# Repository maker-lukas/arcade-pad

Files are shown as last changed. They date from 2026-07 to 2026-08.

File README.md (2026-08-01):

# Pac Pad

> A small arcade pad to play your favorite retro games!

---

This is a small arcade pad i designed and built with hardware i already owned so some of the parts could be better but this is what i had. The layout is a 6x2 button arrangement which covers all the retro classics, plus i added 2 extra buttons on the side for pinball games!! The joystick is just a generic analog module and not a proper arcade joystick but it does the job. For the top panel i used plywood instead of printing it to save on filament and honestly it gives it a nice little look.

for the brains it's running on a ESP32 C3 Super Mini which is not ideal because it doesn't support native USB HID, so i have to power it and connect over BLE bluetooth which adds some latency but its fine for what this is.

## Bill Of Material

| Part | Quantity | Price | Link |
|---|---|---|---|
| 30mm Arcade Button | 8 | $6.21 | [aliexpress](https://aliexpress.com/item/1005010285560262.html) |
| 12mm Tactile Button | 2 | $2.98 | [aliexpress](https://aliexpress.com/item/1005004781630944.html) |
| HW-504 Joystick Module | 1 | $1.81 | [aliexpress](https://aliexpress.com/item/1005006966359366.html) |
| ESP32 C3 Super Mini | 1 | $12.79  | [amazon](https://www.amazon.es/dp/B0DMNBWTFD) |
| Aluminium Tube OD: 10mm ID: 6mm Lenght 500mm | 1 | $5.73 | [aliexpress](https://aliexpress.com/item/1005011781231742.html) |
| m3x14 screws | 10 | $2.23 | [aliexpress](https://aliexpress.com/item/1005005112411362.html) |
| 6.5mm Plywood ~250x150mm | 1 | ~$1 | Local Hardware Store |
| Pin Header 3pins | 1 | $2.12 | [aliexpress](https://aliexpress.com/item/1005008406352332.html) |
| Silicon Wires | 2 | $13.51  | [aliexpress](https://aliexpress.com/item/1005005450546335.html) |
| Female to Female Jumper Cable | 4 | $1.06 | [aliexpress](https://aliexpress.com/item/1005004631908016.html) |
| 3D Printed Parts | 13 | N/A | N/A |
| **Total:** | | ~$49.44 | |

## Flashing

```sh
pip install esptool
esptool.py --chip esp32c3 --port <port> write_flash 0x0 Firmware/Build/pac-pad.ino.merged.bin

Replace `<port>` with your port (e.g. `COM3`, `/dev/ttyACM0`, `/dev/ttyUSB0`).
```

## Overview

| **Schematic**                       |
|:-----------------------------------:|
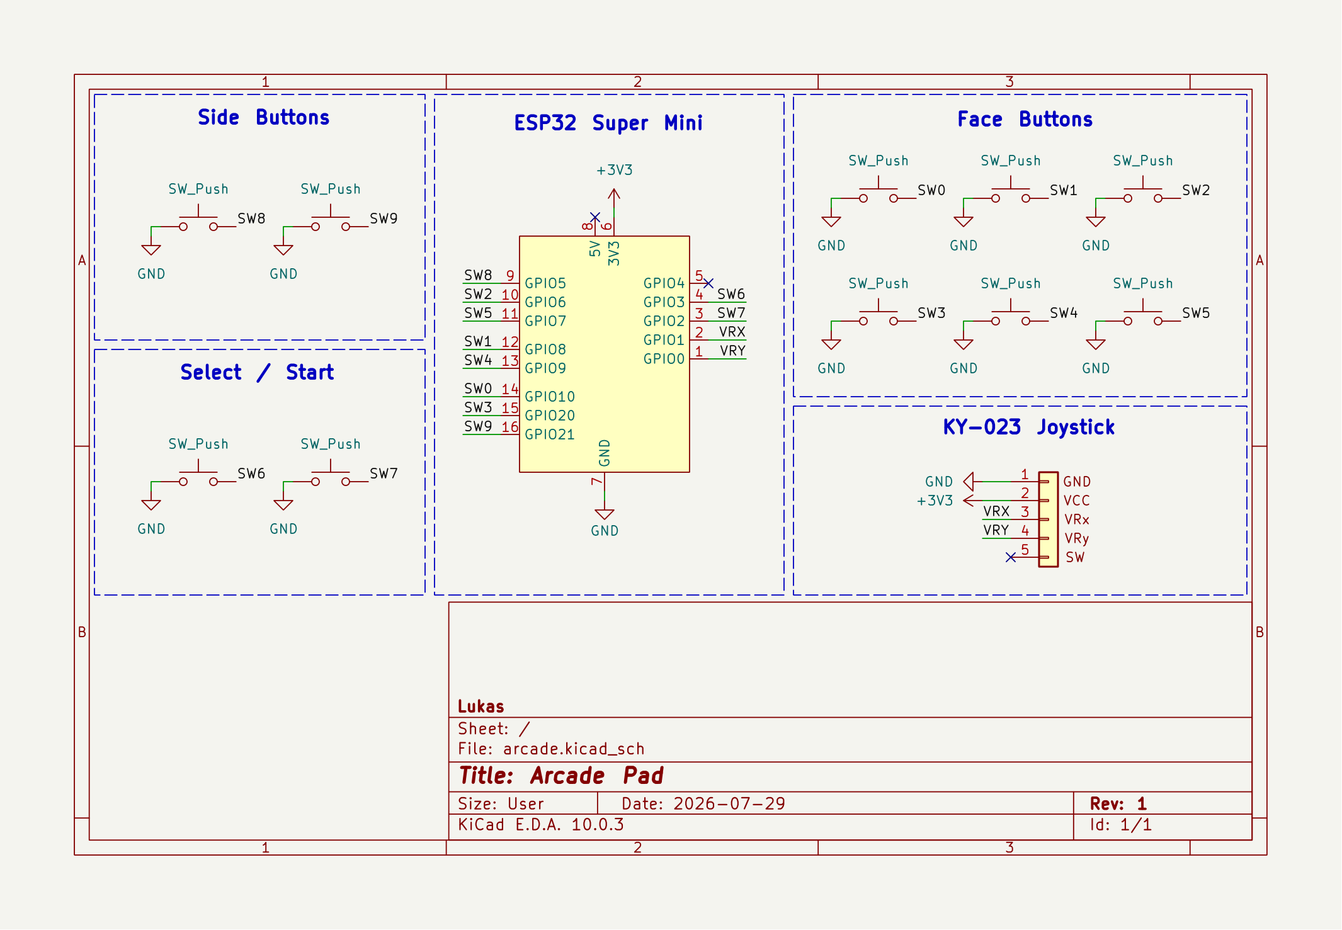
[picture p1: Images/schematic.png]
schematic
|   |
| **Angle View**                      |
| angle view  |
| **Top View**                        |
| Top View    |
| **Bottom View**                     |
| bottom view |
| **Zine**                            |
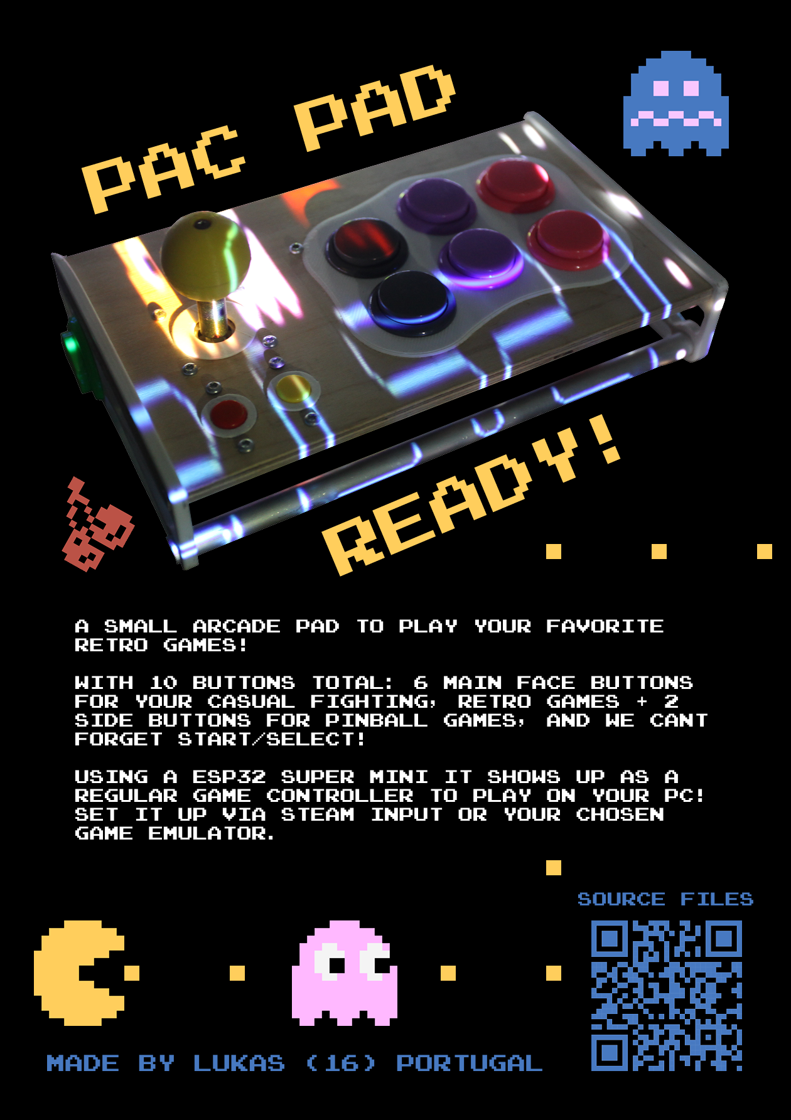
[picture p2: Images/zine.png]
zine
|             |

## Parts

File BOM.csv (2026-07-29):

Part | Quantity | Price | Link
30mm Arcade Button | 8 | $6.21 | https://aliexpress.com/item/1005010285560262.html
12mm Tactile Button | 2 | $2.98 | https://aliexpress.com/item/1005004781630944.html
HW-504 Joystick Module | 1 | $1.81 | https://aliexpress.com/item/1005006966359366.html
ESP32 C3 Super Mini | 1 | $12.79 | https://www.amazon.es/dp/B0DMNBWTFD
Aluminium Tube OD: 10mm ID: 6mm Lenght 500mm | 1 | $5.73 | https://aliexpress.com/item/1005011781231742.html
m3x14 screws | 10 | $2.23 | https://aliexpress.com/item/1005005112411362.html
6.5mm Plywood ~250x150mm | 1 | ~$1 | Local Hardware Store
Pin Header 3pins | 1 | $2.12 | https://aliexpress.com/item/1005008406352332.html
Silicon Wires | 2 | $13.51 | https://aliexpress.com/item/1005005450546335.html
Female to Female Jumper Cable | 4 | $1.06 | https://aliexpress.com/item/1005004631908016.html
3D Printed Parts | 13 | N/A | N/A
Total |  | ~49.44

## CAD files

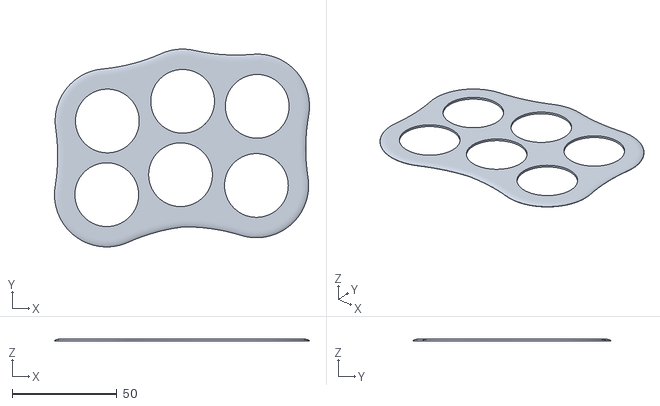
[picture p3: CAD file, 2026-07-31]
3D/Print files/Button Cover.stl
122.0 x 94.6 x 1.00

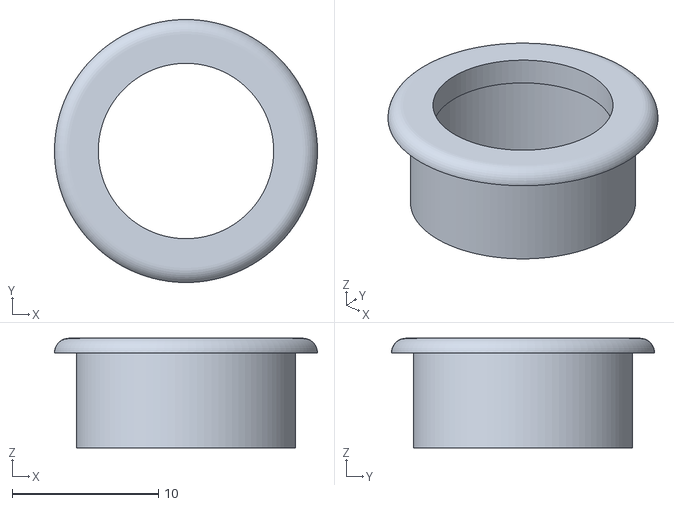
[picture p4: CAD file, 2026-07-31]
3D/Print files/Start_Select Rim.stl
18.0 x 18.0 x 7.50

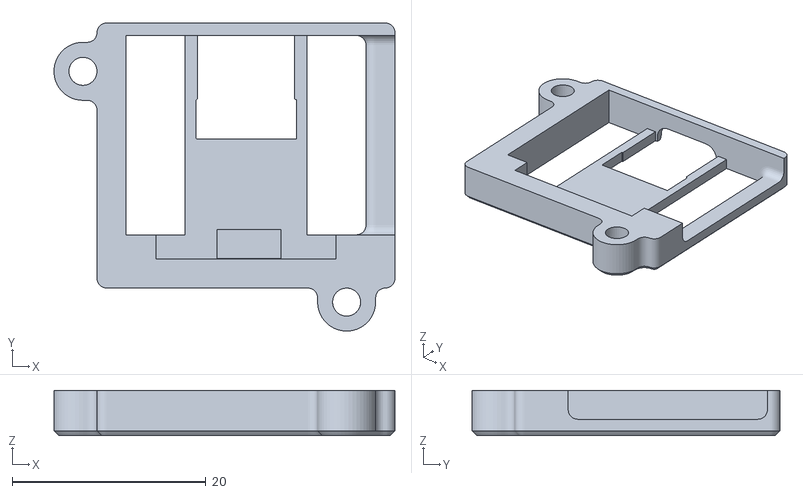
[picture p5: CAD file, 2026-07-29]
3D/Print files/Super Mini Mount.stl
35.2 x 31.8 x 4.70

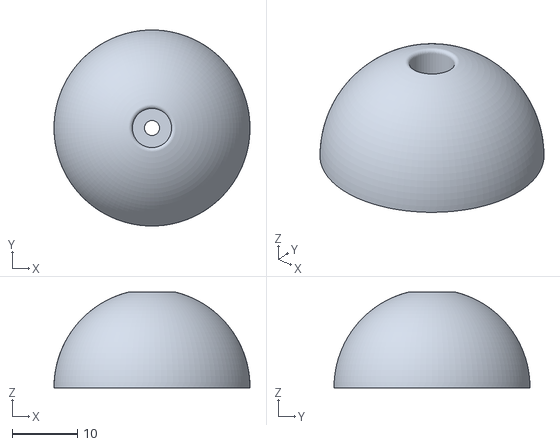
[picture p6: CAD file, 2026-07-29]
3D/Print files/Top Ball.stl
30.0 x 30.0 x 14.7

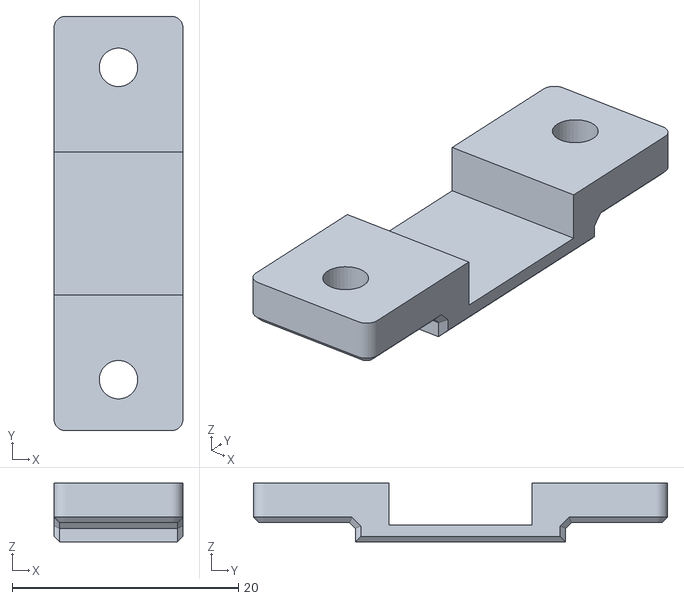
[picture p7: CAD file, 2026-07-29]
3D/Print files/Start_Sellect Bracket.stl
11.4 x 36.6 x 5.20

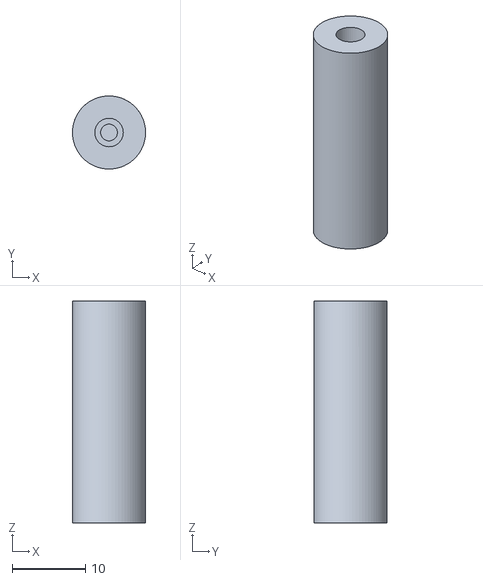
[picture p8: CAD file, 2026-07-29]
3D/Print files/Pole.stl
9.99 x 10.00 x 30.3

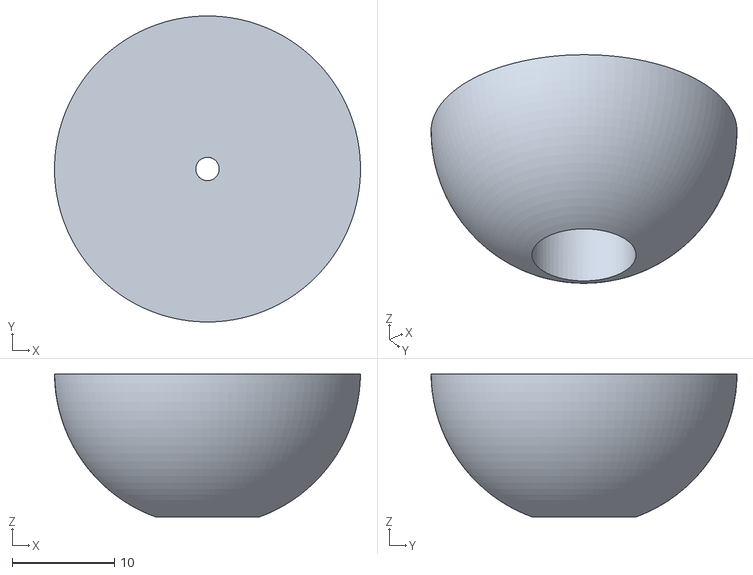
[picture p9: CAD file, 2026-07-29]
3D/Print files/Bottom Ball.stl
30.0 x 30.0 x 14.0

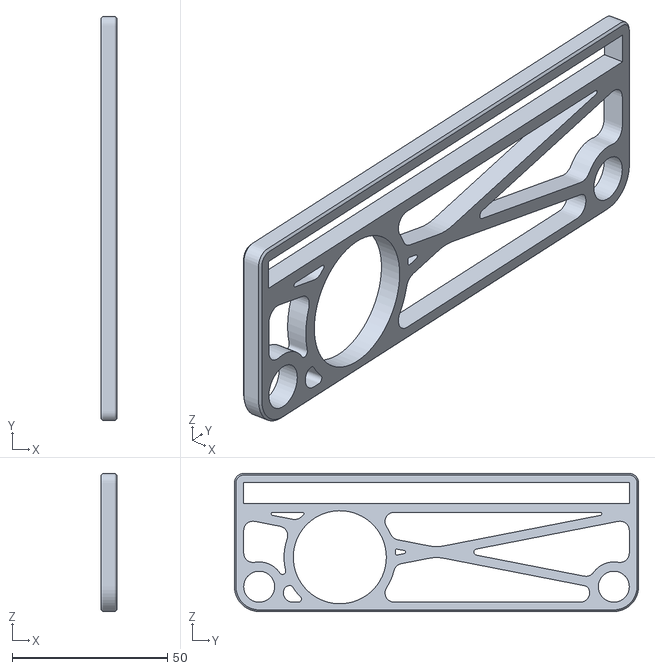
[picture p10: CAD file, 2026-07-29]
3D/Print files/Side Pannel.stl
5.00 x 130.3 x 44.5

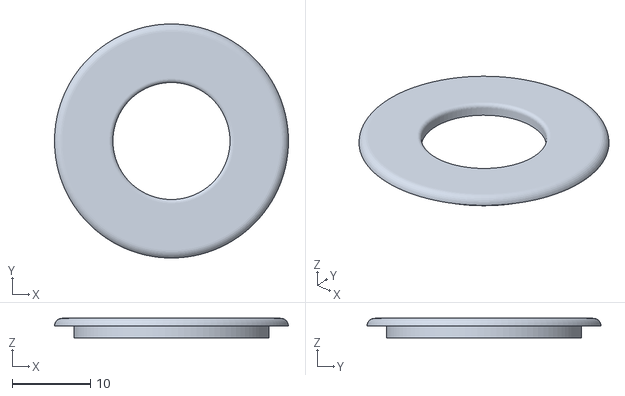
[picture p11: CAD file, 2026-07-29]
3D/Print files/Limiter.stl
30.0 x 30.0 x 2.50

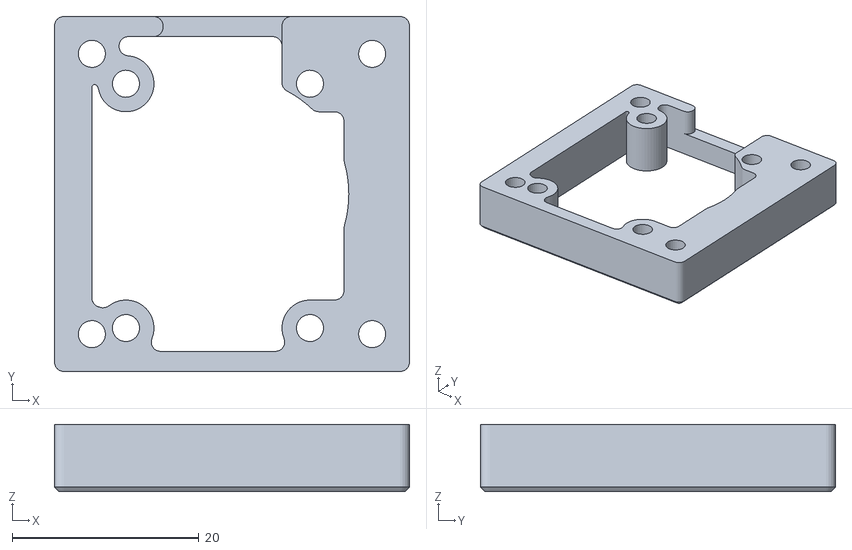
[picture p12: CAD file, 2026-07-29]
3D/Print files/Joystick Mount.stl
38.0 x 38.0 x 7.22

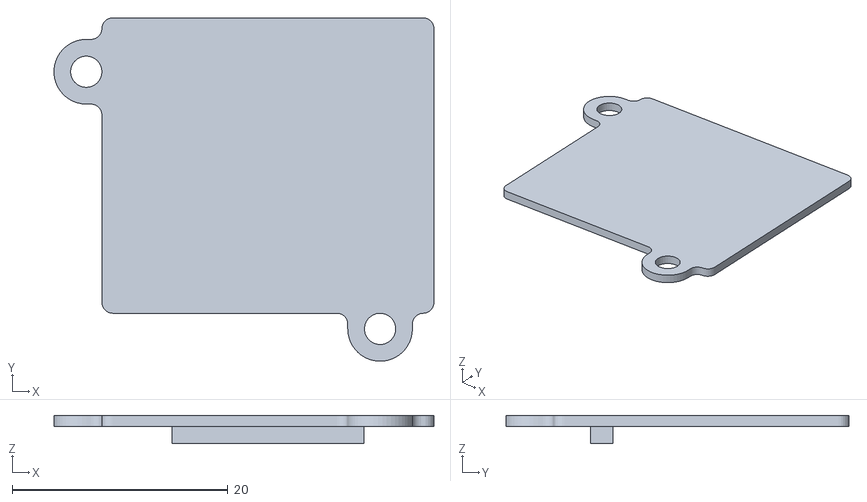
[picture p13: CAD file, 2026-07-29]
3D/Print files/Super Mini Mount Bottom.stl
35.2 x 31.8 x 2.60

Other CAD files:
3D/Print files/button panel.stl

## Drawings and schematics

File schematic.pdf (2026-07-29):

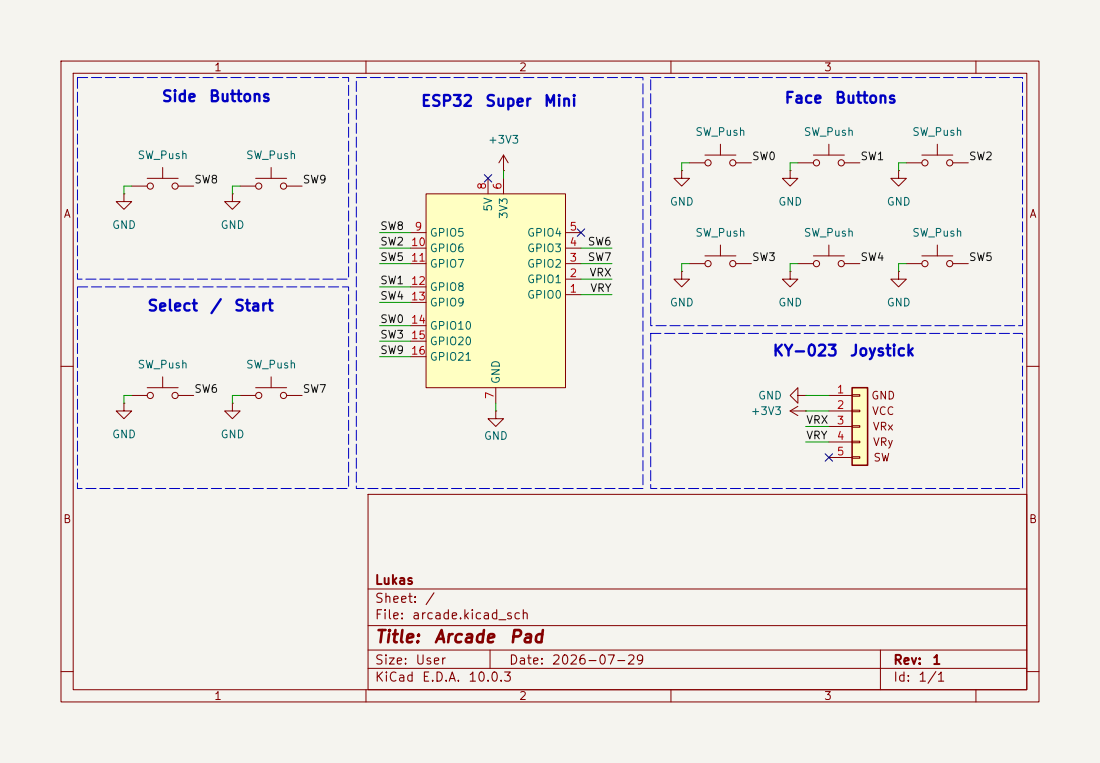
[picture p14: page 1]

Size: User | Rev: 1
KiCad E.D.A. 10.0.3 | Id: 1/1

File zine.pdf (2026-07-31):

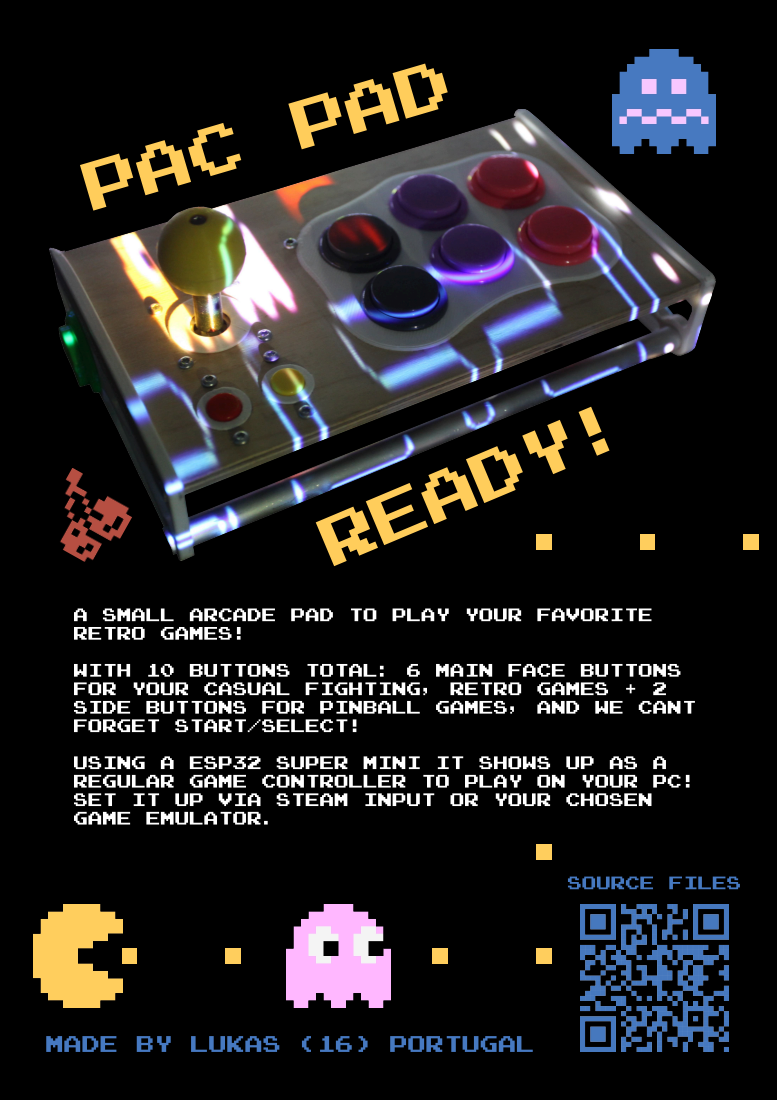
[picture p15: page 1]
Pac Pad; Ready!; Source; files; made; Lukas (16); Portugal

A small arcade pad to play your favorite
retro games!

with 10 buttons total: 6 main face buttons
for your casual fighting, retro games + 2
side buttons for pinball games, and we cant
forget start/select!

Using a esp32 super mini it shows up as a
regular game controller to play on your pc!
set it up via steam input or your chosen
game emulator.

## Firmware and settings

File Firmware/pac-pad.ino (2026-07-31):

#include <ESP32BLECombo.h>

constexpr uint8_t PIN_JOY_X = 0;
constexpr uint8_t PIN_JOY_Y = 1;

constexpr uint8_t BUTTON_COUNT = 10;
constexpr uint8_t BUTTON_PINS[BUTTON_COUNT] = {
    10, 8, 6,
    20, 9, 7,
    2, 3,
    21, 5,
};

constexpr unsigned long DEBOUNCE_MS = 20;
constexpr int ADC_MAX = 4095;
constexpr int JOYSTICK_DEADZONE = 200;
constexpr int16_t AXIS_CHANGE_THRESHOLD = 256;

ESP32BLECombo gamepad;
bool rawPressed[BUTTON_COUNT] = {};
bool stablePressed[BUTTON_COUNT] = {};
unsigned long lastChangeMs[BUTTON_COUNT] = {};
uint16_t buttonState = 0;
bool wasConnected = false;

int joyCenterX = 2048;
int joyCenterY = 2048;
int16_t currentAxisX = 0;
int16_t currentAxisY = 0;
int16_t sentAxisX = 0;
int16_t sentAxisY = 0;

int readAveragedAxis(uint8_t pin) {
    int total = 0;
    for (uint8_t i = 0; i < 4; ++i) {
        total += analogRead(pin);
    }
    return total / 4;
}

int16_t scaleAxis(int raw, int center) {
    const int delta = raw - center;
    if (abs(delta) <= JOYSTICK_DEADZONE) {
        return 0;
    }

    if (delta > 0) {
        const int positiveRange = max(ADC_MAX - center - JOYSTICK_DEADZONE, 1);
        const int32_t value = (int32_t)(delta - JOYSTICK_DEADZONE) * 32767 / positiveRange;
        return (int16_t)constrain(value, 0L, 32767L);
    }

    const int negativeRange = max(center - JOYSTICK_DEADZONE, 1);
    const int32_t value = (int32_t)(-delta - JOYSTICK_DEADZONE) * 32767 / negativeRange;
    return (int16_t)-constrain(value, 0L, 32767L);
}

void calibrateJoystick() {
    int32_t sumX = 0;
    int32_t sumY = 0;

    Serial.println("keep the thumb stick centered");
    delay(300);
    for (uint16_t i = 0; i < 256; ++i) {
        sumX += analogRead(PIN_JOY_X);
        sumY += analogRead(PIN_JOY_Y);
        delay(2);
    }

    joyCenterX = sumX / 256;
    joyCenterY = sumY / 256;
    Serial.printf("joystick center: X=%d Y=%d\n", joyCenterX, joyCenterY);
}

void updateButtons(unsigned long now, bool connected) {
    bool stateChanged = false;

    for (uint8_t i = 0; i < BUTTON_COUNT; ++i) {
        const bool pressed = digitalRead(BUTTON_PINS[i]) == LOW;

        if (pressed != rawPressed[i]) {
            rawPressed[i] = pressed;
            lastChangeMs[i] = now;
        }

        if (pressed != stablePressed[i] &&
            now - lastChangeMs[i] >= DEBOUNCE_MS) {
            stablePressed[i] = pressed;
            if (pressed) {
                buttonState |= (1u << i);
            } else {
                buttonState &= ~(1u << i);
            }
            stateChanged = true;
        }
    }
    if (connected && wasConnected && stateChanged) {
        gamepad.gamepadSetButtons(buttonState);
    }
}

void updateJoystick(bool connected) {
    currentAxisX = -scaleAxis(readAveragedAxis(PIN_JOY_X), joyCenterX);
    currentAxisY = scaleAxis(readAveragedAxis(PIN_JOY_Y), joyCenterY);

    const bool returnedToCenter =
        (currentAxisX == 0 && sentAxisX != 0) ||
        (currentAxisY == 0 && sentAxisY != 0);
    const bool movedEnough =
        abs((int32_t)currentAxisX - sentAxisX) >= AXIS_CHANGE_THRESHOLD ||
        abs((int32_t)currentAxisY - sentAxisY) >= AXIS_CHANGE_THRESHOLD;

    if (connected && wasConnected && (returnedToCenter || movedEnough)) {
        gamepad.gamepadSetAxes(currentAxisX, currentAxisY);
        sentAxisX = currentAxisX;
        sentAxisY = currentAxisY;
    }
}

void setup() {
    Serial.begin(115200);
    delay(500);
    Serial.println("starting Pac Pad ");

    for (uint8_t i = 0; i < BUTTON_COUNT; ++i) {
        pinMode(BUTTON_PINS[i], INPUT_PULLUP);
        rawPressed[i] = digitalRead(BUTTON_PINS[i]) == LOW;
        stablePressed[i] = rawPressed[i];
        lastChangeMs[i] = millis();
        if (stablePressed[i]) {
            buttonState |= (1u << i);
        }
    }

    analogReadResolution(12);
    calibrateJoystick();

    ESP32BLEComboConfig config;
    config.mode = ESP32BLEComboMode::GAMEPAD_ONLY;
    config.gamepadLayout = ESP32BLEGamepadLayout::GENERIC;
    config.deviceName = "Pac Pad";
    config.manufacturer = "Espressif";
    config.appearance = ESP32BLEComboAppearance::GAMEPAD;
    config.enableSecurity = true;

    if (!gamepad.begin(config)) {
        Serial.println("failed to start Pac Pad");
        return;
    }

    Serial.println("ready to pair as a game controller");
}

void loop() {
    const unsigned long now = millis();
    const bool connected = gamepad.isConnected();

    updateButtons(now, connected);
    updateJoystick(connected);

    if (connected && !wasConnected) {
        gamepad.gamepadSetButtons(buttonState);
        gamepad.gamepadSetAxes(currentAxisX, currentAxisY);
        gamepad.gamepadSetHat(ESP32BLECombo::HAT_CENTERED);
        sentAxisX = currentAxisX;
        sentAxisY = currentAxisY;
        Serial.println("gamepad connected");
    } else if (!connected && wasConnected) {
        Serial.println("gamepad disconnected");
    }

    wasConnected = connected;
    delay(5);
}

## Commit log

2026-07-29 add all the shiz
    [Bottom Ball.stl, Joystick Mount.stl, Limiter.stl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]
2026-07-29 add stuff to README and add BOM.csv
    [BOM.csv]
2026-07-29 fix BOM.CSV
    [BOM.csv]
2026-07-31 add full 3D files
    [Button Cover.stl, Start_Select Rim.stl]
2026-07-31 rebrand firmware from arcade pad to pac pad
    [partitions.csv]
2026-08-01 push new folder placement
    [partitions.csv]
